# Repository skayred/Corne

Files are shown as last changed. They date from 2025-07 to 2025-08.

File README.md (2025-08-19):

# Budget Wireless Corne Keyboard Build

A DIY wireless split keyboard based on the Corne layout, built for approximately $25 USD. This project uses a ProMicro clone with nrf52840 chip, making it a cost-effective alternative to traditional wireless split keyboard builds.

## Features
- Fully wireless using Bluetooth
- Split ergonomic design (Corne layout)
- Low profile design for portability
- Battery-powered with power switch
- ZMK firmware
- Estimated battery life: 1+ month

## Bill of Materials

| Component | Quantity | Cost (USD) | Link |
|---|---|---|---|
| Controller boards (ProMicro nrf52840) | 2 | 6.82 | [AliExpress](https://a.aliexpress.com/_EIV3vwY) |
| Batteries | 2 | 4.20 | [AliExpress](https://a.aliexpress.com/_Eynt9TK) |
| Mechanical Switches | 50 | 7.47 | [AliExpress](https://a.aliexpress.com/_EGhMxEC) |
| Keycaps | Set | 3.79 | [Option 1](https://a.aliexpress.com/_EzQyNtA) / [Option 2](https://a.aliexpress.com/_EH8mNqs) |
| Diodes (1N4148) | 100 | 0.85 | [AliExpress](https://a.aliexpress.com/_EwZoG2G) |
| Slide Switches | 2 | 0.11 | |
| 3D Printed Parts | Set | 1.80 | Files provided |

**Total Cost**: $25.04 (excluding wires and screws)

## Current Keymap







## Build Instructions

### Prerequisites
- Basic soldering skills
- Access to a 3D printer
- Basic understanding of keyboard firmware

### Case Assembly
1. Print the case files (STL files provided in `3DFiles` directory)
2. Note: You may need to adjust the:
   - Battery compartment size
   - Slide switch holes

### Wiring
1. Wire switches in a matrix configuration
2. Connect diodes:
   - Direction matters (black line indicates cathode)
   - Use diode legs for the rows
   - Use separate wires for columns
3. Keep wiring clear of screw holes
4. Connect the battery:
   - GND to GND pin
   - Positive to one of the side legs on the slide switch
   - Middle pin of the slide switch to the RAW pin

### Pin Connections for Rows and Columns
The matrix configuration uses GPIO pins on the nRF52840 Pro Micro clone. Below are the connections:

pinout

#### How Rows and Columns Are Numbered

- **Rows**: Rows are always numbered from top to bottom on both halves.
- **Columns**: Columns are always numbered from left to right (as viewed from the back of the plate (where the wiring is done)).

⚠️ **Note**: If you accidentally solder the rows or columns to the wrong pins, you do not need to desolder. The mappings can be fixed in the firmware configuration files:
- `corne.dtsi`: Defines rows for both halves.
- `corne_left.overlay`: Defines columns for the left half.
- `corne_right.overlay`: Defines columns for the right half.

#### Left Half Pin Assignments
- **Rows (Connected to `row-gpios`)**:
  - Row 0: Pin 21
  - Row 1: Pin 20
  - Row 2: Pin 19
  - Row 3: Pin 18
- **Columns (Connected to `col-gpios`)**:
  - Column 0: Pin 2
  - Column 1: Pin 7
  - Column 2: Pin 6
  - Column 3: Pin 5
  - Column 4: Pin 4
  - Column 5: Pin 3

#### Right Half Pin Assignments
- **Rows (`row-gpios`)**:
  - Row 0: Pin 21
  - Row 1: Pin 20
  - Row 2: Pin 19
  - Row 3: Pin 18
- **Columns (`col-gpios`)**:
  - Column 0: Pin 3
  - Column 1: Pin 4
  - Column 2: Pin 5
  - Column 3: Pin 6
  - Column 4: Pin 7
  - Column 5: Pin 2

### Firmware Setup
This keyboard uses ZMK firmware. The left half acts as the main controller that connects to your device.

To flash the firmware:
1. Double press the reset button
2. Board will appear as mass storage device
3. Flash the appropriate firmware file

If you forgot the keyboard from your device and can't reconnect:
1. Flash the `settings_reset-nice_nano_v2-zmk.uf2` file
2. Reflash the regular firmware
3. Pair

## Repository Structure
```
├── .github/workflows/
│   └── build.yml
├── 3DFiles/
│   ├── STEP/
│   │   └── CorneSTEP.step
│   ├── STL/
│   │   ├── Case_Left.stl
│   │   ├── Case_Right.stl
│   │   └── PlateCorne.stl
├── config/
│   ├── boards/shields/corne/
│   │   ├── corne_left.conf
│   │   ├── corne_left.overlay
│   │   ├── corne_right.conf
│   │   ├── corne_right.overlay
│   │   ├── corne.conf
│   │   ├── corne.dtsi
│   │   ├── Kconfig.defconfig
│   │   └── Kconfig.shield
│   ├── corne.keymap
│   └── west.yml
├── firmware/
│   ├── corne_left-nice_nano_v2-zmk.uf2
│   ├── corne_right-nice_nano_v2-zmk.uf2
│   └── settings_reset-nice_nano_v2-zmk.uf2
└── zephyr/
    ├── module.yml
    └── build.yaml
```

## Known Issues
- Left side case may have warping issues if battery swells
- Slide switch holes may need adjustment based on your components

## Final result
im1
im3

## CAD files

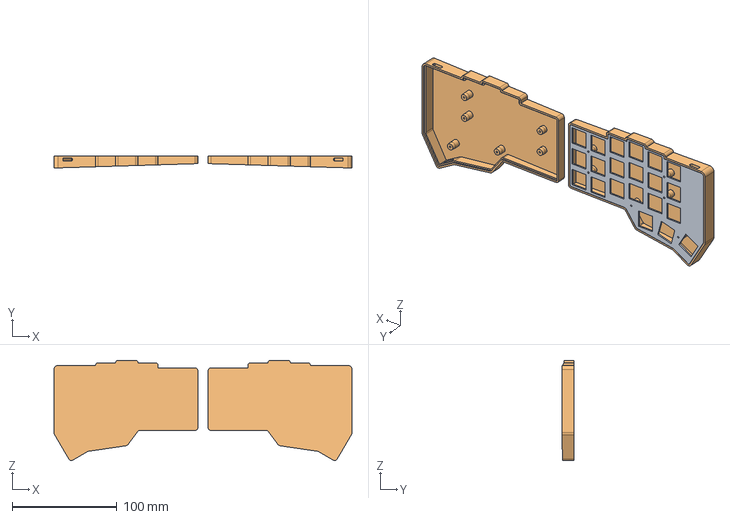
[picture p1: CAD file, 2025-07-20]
3DFiles/STEP/CorneSTEP.step
284.0 x 11.5 x 95.4 mm

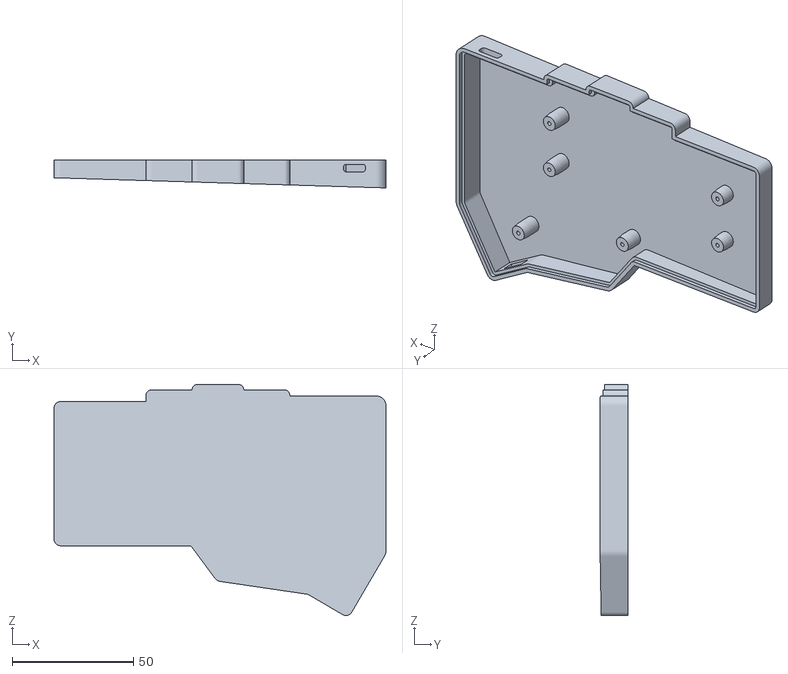
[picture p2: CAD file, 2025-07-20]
3DFiles/STL/Case_Right.stl
137.1 x 11.5 x 95.4

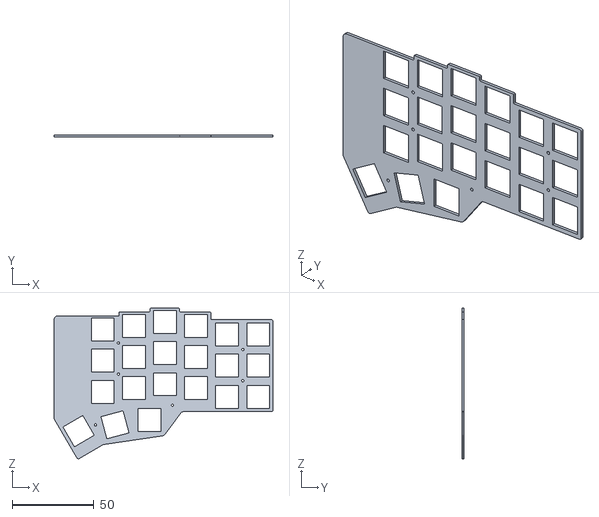
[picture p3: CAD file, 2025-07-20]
3DFiles/STL/PlateCorne.stl
133.8 x 1.35 x 92.0

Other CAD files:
3DFiles/STL/Case_Left.stl

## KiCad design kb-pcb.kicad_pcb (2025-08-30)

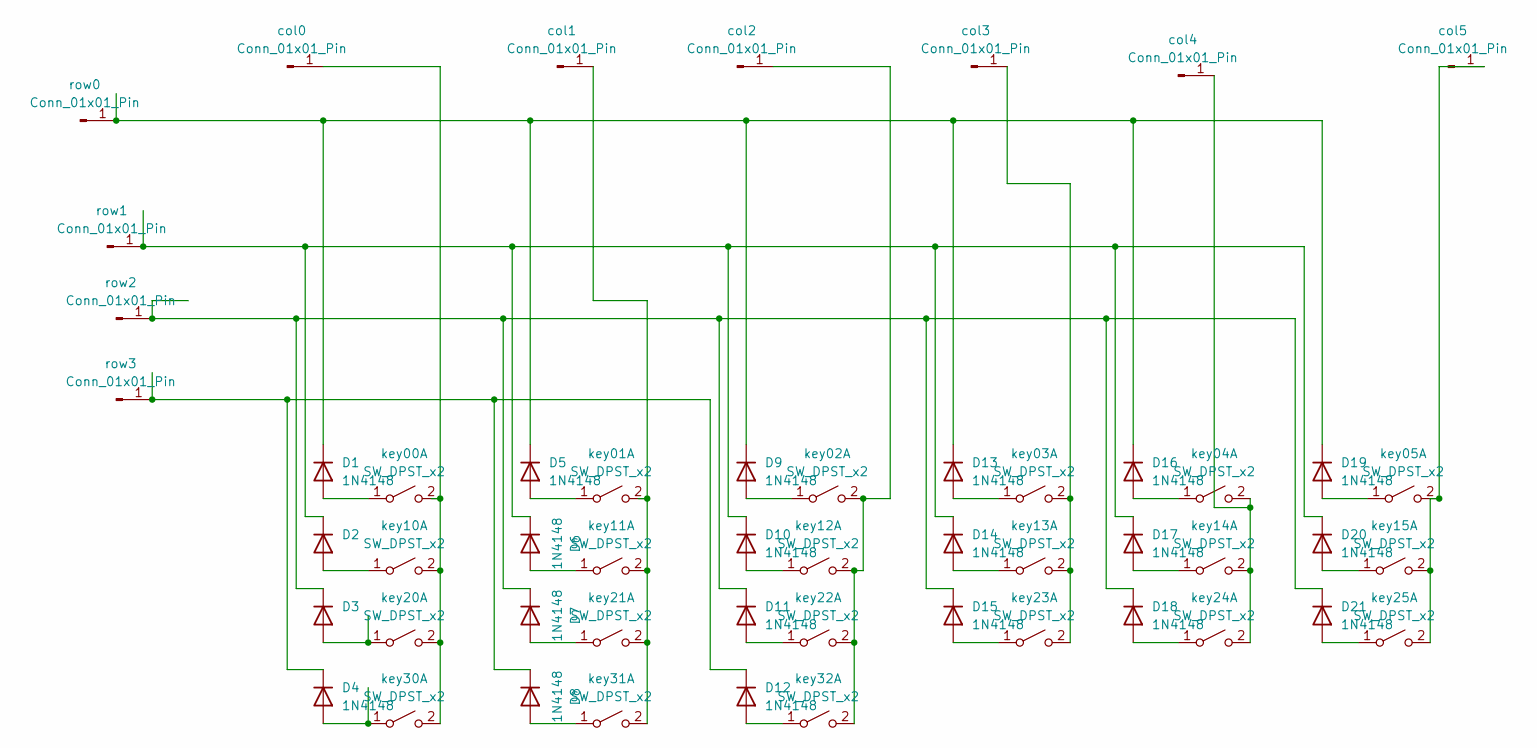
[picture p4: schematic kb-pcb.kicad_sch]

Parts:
D1, D2, D3, D4, D5, D6, D7, D8, D9, D10, D11, D12, D13, D14, D15, D16, D17, D18, D19, D20, D21: 1N4148; D_DO-35_SOD27_P7.62mm_Horizontal
col0, col1, col2, col3, col4, col5: Conn_01x01_Pin; PinSocket_1x01_P1.27mm_Vertical
key00, key01, key02, key03, key04, key05, key10, key11, key12, key13, key14, key15, key20, key21, key22, key23, key24, key25, key30, key31, key32: SW_DPST_x2; SW_Redragon_LowProfile_PCB_1.00u
row0, row1, row2, row3: Conn_01x01_Pin; PinSocket_1x01_P1.27mm_Vertical

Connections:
unnamed: D1.2 (A), key00.1 (A)
unnamed: D1.1 (K), D5.1 (K), D9.1 (K), D13.1 (K), D16.1 (K), D19.1 (K), row0.1
unnamed: D2.2 (A), key10.1 (A)
unnamed: D3.2 (A), key20.1 (A)
unnamed: D4.2 (A), key30.1 (A)
unnamed: D5.2 (A), key01.1 (A)
unnamed: D6.2 (A), key11.1 (A)
unnamed: D7.2 (A), key21.1 (A)
unnamed: D8.2 (A), key31.1 (A)
unnamed: D9.2 (A), key02.1 (A)
unnamed: D10.2 (A), key12.1 (A)
unnamed: D2.1 (K), D6.1 (K), D10.1 (K), D14.1 (K), D17.1 (K), D20.1 (K), row1.1
unnamed: D11.2 (A), key22.1 (A)
unnamed: D3.1 (K), D7.1 (K), D11.1 (K), D15.1 (K), D18.1 (K), D21.1 (K), row2.1
unnamed: D12.2 (A), key32.1 (A)
unnamed: D4.1 (K), D8.1 (K), D12.1 (K), row3.1
unnamed: D13.2 (A), key03.1 (A)
unnamed: D14.2 (A), key13.1 (A)
unnamed: D15.2 (A), key23.1 (A)
unnamed: D16.2 (A), key04.1 (A)
unnamed: D17.2 (A), key14.1 (A)
unnamed: D18.2 (A), key24.1 (A)
unnamed: D19.2 (A), key05.1 (A)
unnamed: D20.2 (A), key15.1 (A)
unnamed: D21.2 (A), key25.1 (A)
unnamed: col0.1, key00.2 (B), key10.2 (B), key20.2 (B), key30.2 (B)
unnamed: col1.1, key01.2 (B), key11.2 (B), key21.2 (B), key31.2 (B)
unnamed: col2.1, key02.2 (B), key12.2 (B), key22.2 (B), key32.2 (B)
unnamed: col3.1, key03.2 (B), key13.2 (B), key23.2 (B)
unnamed: col4.1, key04.2 (B), key14.2 (B), key24.2 (B)
unnamed: col5.1, key05.2 (B), key15.2 (B), key25.2 (B)

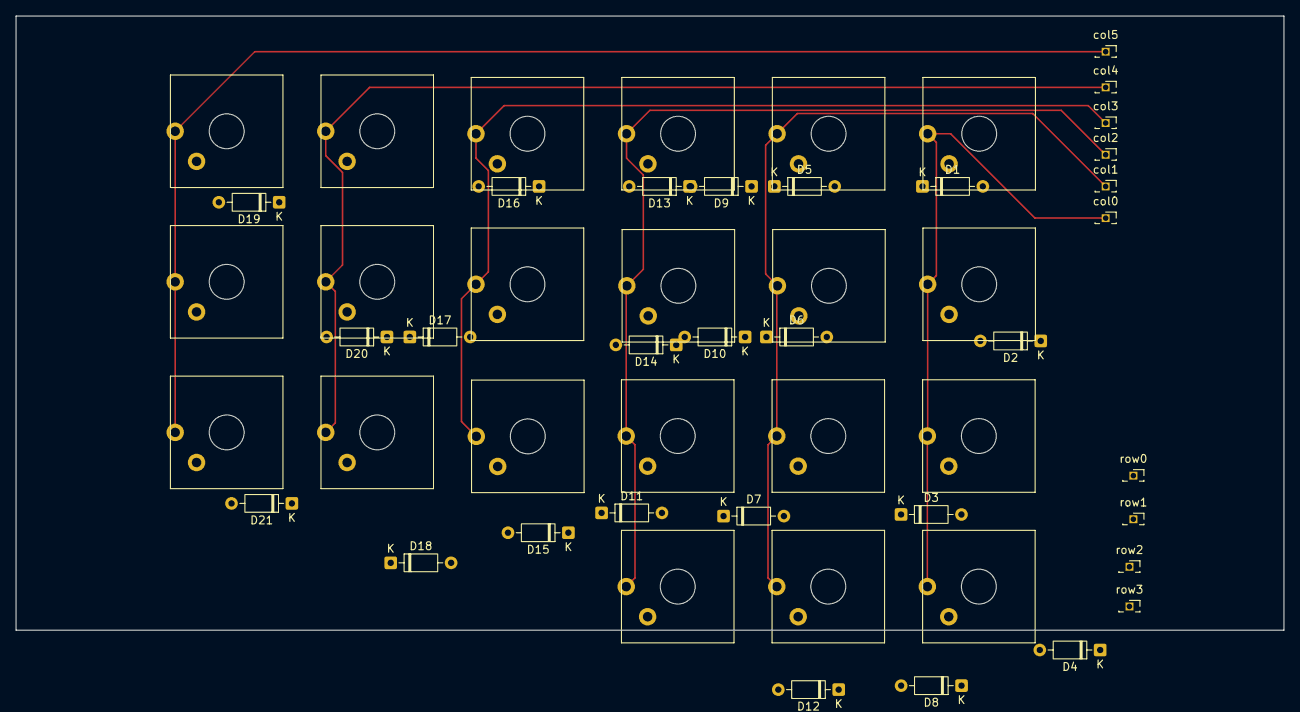
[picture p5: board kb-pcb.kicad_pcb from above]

Board: 2 copper layers, 160.0 x 77.5 mm, 52 parts (0 on the bottom side), 31 nets.

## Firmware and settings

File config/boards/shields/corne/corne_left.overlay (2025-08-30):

#include "corne.dtsi"

&kscan0 {
    col-gpios = <&pro_micro 2 GPIO_ACTIVE_HIGH>,
                <&pro_micro 3 GPIO_ACTIVE_HIGH>,
                <&pro_micro 4 GPIO_ACTIVE_HIGH>,
                <&pro_micro 5 GPIO_ACTIVE_HIGH>,
                <&pro_micro 6 GPIO_ACTIVE_HIGH>,
                <&pro_micro 7 GPIO_ACTIVE_HIGH>;
};


#define MOUSE_PS2_DRIVER_UART
#define MOUSE_PS2_PIN_SCL_PRO_MICRO <&pro_micro 1 GPIO_ACTIVE_HIGH>
#define MOUSE_PS2_PIN_SDA_PRO_MICRO <&pro_micro 0 GPIO_ACTIVE_HIGH>
#define MOUSE_PS2_PIN_RST_PRO_MICRO <&pro_micro 9 GPIO_ACTIVE_HIGH>
#define MOUSE_PS2_PIN_SDA_PINCTRL <NRF_PSEL(UART_RX, 0, 8)>
#define MOUSE_PS2_UART_BAUD_RATE <14400>


/*
 * PS/2 Mouse / Trackpoint - User Configuration if NOT using nice!nano
 *
 * WARNING: Do NOT change this if you are using a nice!nano v2 or clone.
 */

// Unexposed UART pins
// In UART two different pins are used for receiving and transmitting, but PS/2
// uses the same pin for both.
//
// The UART config still requires both pins to be configured. So we use one of
// the nrf52 pins that are not exposed on the nice!nano board.
//
// Do NOT change these if you are using a nice!nano (or a clone of it)
#define MOUSE_PS2_PIN_UNEXPOSED_TX <NRF_PSEL(UART_TX, 0, 27)>
#define MOUSE_PS2_PIN_UNEXPOSED_RX <NRF_PSEL(UART_RX, 0, 28)>


// Adjust GPIO interrupt priority to the highest level.
//
// IMPORTANT TLDR:
// If you are using the nice_nano_v2 board, you don't need to make changes to
// the config below and can leave it as it is.
//
// Explanation of these settings:
//
// PS/2 events must be processed within 30-50us, but frequently bluetooth and
// other interrupts take longer to finish.
//
// Therefore we change the default GPIO priority to the highest level (0) and
// demote all BT interrupt priorities by one level using the kconfig settings:
// - CONFIG_BT_CTLR_LLL_PRIO 1
// - CONFIG_BT_CTLR_ULL_HIGH_PRIO 2
// - CONFIG_BT_CTLR_ULL_LOW_PRIOCONFIG 2
//
// These config options are enabled automatically by the PS2 UART and GPIO
// drivers... so you don't have to enable them manually.
//
// Then we lower the interrupt priority of all other devices by 2 levels using
// the devicetree config below.
//
// This allows the PS/2 interrupts to be triggered faster and reduces
// transmission errors.
//
// If you are using the nice_nano_v2 board, you can reuse my config below.
//
// Otherwise, you can generate the interrupt overrides using this script:
// https://github.com/infused-kim/kb_zmk_ps2_mouse_trackpoint_driver/blob/main/scripts/gen_interrupt_priority_overrides.py
//
// Make sure to do it on a zephyr.dts where the interrupts have not been
// adjusted yet (i.e. a config that doesn't have the the following options
// enabled).
//
// If you are building using a toolchain you can find the zephyr.dts in the
// build directory, which by default is: `app/build/zephyr/zephyr.dts`
//
// If you are building using the github actions, copy the output of the build
// step `xxxx_right - nice_nano_v2 Devicetree file` into a file and run the
// script on it.

// gpiote should have the highest interrupt priority (0)
&gpiote {
    interrupts = < 6 0 >;
};

// All other priorities should be two levels lower than their defaults
// (which is usually 1 and should be demoted to 3)
&clock {
    interrupts = < 0 3 >;
};

&power {
    interrupts = < 0 3 >;
};

&radio {
    interrupts = < 1 3 >;
};

&uart0 {
    interrupts = < 2 3 >;
};

&i2c0 {
    interrupts = < 3 3 >;
};

&spi0 {
    interrupts = < 3 3 >;
};

&i2c1 {
    interrupts = < 4 3 >;
};

&spi1 {
    interrupts = < 4 3 >;
};

&nfct {
    interrupts = < 5 3 >;
};

&adc {
    interrupts = < 7 3 >;
};

&timer0 {
    interrupts = < 8 3 >;
};

&timer1 {
    interrupts = < 9 3 >;
};

&timer2 {
    interrupts = < 10 3 >;
};

&rtc0 {
    interrupts = < 11 3 >;
};

&temp {
    interrupts = < 12 3 >;
};

&rng {
    interrupts = < 13 3 >;
};

&ecb {
    interrupts = < 14 3 >;
};

&ccm {
    interrupts = < 15 3 >;
};

&wdt {
    interrupts = < 16 3 >;
};

&rtc1 {
    interrupts = < 17 3 >;
};

&qdec {
    interrupts = < 18 3 >;
};

&comp {
    interrupts = < 19 3 >;
};

&egu0 {
    interrupts = < 20 3 >;
};

&egu1 {
    interrupts = < 21 3 >;
};

&egu2 {
    interrupts = < 22 3 >;
};

&egu3 {
    interrupts = < 23 3 >;
};

&egu4 {
    interrupts = < 24 3 >;
};

&egu5 {
    interrupts = < 25 3 >;
};

&timer3 {
    interrupts = < 26 3 >;
};

&timer4 {
    interrupts = < 27 3 >;
};

&pwm0 {
    interrupts = < 28 3 >;
};

&pdm0 {
    interrupts = < 29 3 >;
};

&pwm1 {
    interrupts = < 33 3 >;
};

&pwm2 {
    interrupts = < 34 3 >;
};

&spi2 {
    interrupts = < 35 3 >;
};

&rtc2 {
    interrupts = < 36 3 >;
};

&i2s0 {
    interrupts = < 37 3 >;
};

&usbd {
    interrupts = < 39 3 >;
};

&uart1 {
    interrupts = < 40 3 >;
};

&qspi {
    interrupts = < 41 3 >;
};

&pwm3 {
    interrupts = < 45 3 >;
};

&spi3 {
    interrupts = < 47 3 >;
};

&cryptocell {
    interrupts = < 42 3 >;
};
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

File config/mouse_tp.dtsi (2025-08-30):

#ifdef HAS_MOUSE_TP
  #include <dt-bindings/zmk/mouse.h>
  #include <dt-bindings/zmk/mouse_settings.h>
  #include <behaviors/mouse_keys.dtsi>
  #include <behaviors/mouse_setting.dtsi>

 /*
  * Key Behaviors to adjust settings
  */

  // They key codes below can be used to adjust the TP settings at runtime
  // without needing to recompile the firmware.
  //
  // The values will be logged and saved in the config on the controller flash
  // after 60s (CONFIG_ZMK_SETTINGS_SAVE_DEBOUNCE).
  //
  // On boot the settings will be restored again.
  //
  // If you prefer a more explicit way of configuration, you can also hardcode
  // these settings in `&mouse_ps2`.
  //
  // If you set these settings in `&mouse_ps2`, you will still be able to
  // adjust the values during runtime with these key codes, but after
  // restarting the board the values in `&mouse_ps2` will be restored and not
  // the ones stored in the flash using the key codes.


  // How sensitive the trackpoint is
  #define U_MSS_TP_S_I &mms MS_TP_SENSITIVITY_INCR
  #define U_MSS_TP_S_D &mms MS_TP_SENSITIVITY_DECR


  // The maximum speed the trackpoint will accelerate to
  #define U_MSS_TP_V6_I &mms MS_TP_VALUE6_INCR
  #define U_MSS_TP_V6_D &mms MS_TP_VALUE6_DECR


  // I am not quite sure tbh... default seems fine.
  #define U_MSS_TP_NI_I &mms MS_TP_NEG_INERTIA_INCR
  #define U_MSS_TP_NI_D &mms MS_TP_NEG_INERTIA_DECR


  // How hard you have to press to activate the "Press To Select" feature that
  // lets you tap or press on the trackpoint to click.
  //
  // Not all trackpoints support it and you have to enable
  // `tp-press-to-select;` in `&mouse_ps2` first.
  #define U_MSS_TP_PT_I &mms MS_TP_PTS_THRESHOLD_INCR
  #define U_MSS_TP_PT_D &mms MS_TP_PTS_THRESHOLD_DECR


  // If you mess up the settings, you can use this key code to clear the
  // settings from flash and re-set the default values on the TP.
  //
  // Make sure to wait at least CONFIG_ZMK_SETTINGS_SAVE_DEBOUNCE seconds (60
  // by default) before restarting the board to ensure the settings are
  // written to flash storage.
  #define U_MSS_RESET   &mms MS_RESET


  // If you prefer to set the settings in `&mouse_ps2`, you can use the key
  // codes above to find the settings you like the most and then press this
  // key code to output the settings to the log.
  //
  // Then you can add those values to `&mouse_ps2`
  #define U_MSS_LOG     &mms MS_LOG


  // Only apply these settings on the side that has the TP connected
  // (usually the right side)
  #ifdef MOUSE_PS2_DT_PRESENT

   /*
    * Input Listener Config
    */

    &mouse_ps2_input_listener {

      // Adjust pointing device axes.
      // This adjusts the values inside the zmk driver. Some
      // trackpoints also allow you to adjust it in their firmware. Check
      // the driver options below for more info.
      // xy-swap;
      // x-invert;
      // y-invert;

      // Set the layer that should automatically activate when the mouse is
      // moving.
      layer-toggle = <MOUSE_TP>;

      // How long the mouse needs to move for before the layer is activated (to
      // avoid accidental activations while typing) (Default: 250)
      layer-toggle-delay-ms = <250>;

      // How long to wait, after the last mouse movement, before deactivating
      // the layer (Default: 250)
      layer-toggle-timeout-ms = <250>;
    };


   /*
    * Mouse Driver Settings
    */

    &mouse_ps2 {

      // How sensitive the TP is (Default: 128)
      // tp-sensitivity = <128>;


      // The maximum mouse movement speed the TP will accelarate to
      // (Default: 97)
      // tp-val6-upper-speed = <97>;


      // Negative Inertia (Default: 6)
      // Makes the TP feel more responsive and "overshoot" less.
      // tp-neg-inertia = <6>;


      // Enable clicking by tapping on the TP.
      // Not all TPs support this.
      // tp-press-to-select;
      // tp-press-to-select-threshold = <10>;


      // Adjust axis settings on the TP
      // Works only on some trackpoints, but may be properly considered by the
      // trackpoint's acceleration features (which may or may not have an
      // impact).
      //
      // Alternatively consider achieving the same effect using the
      //  `input-listener` settings below.
      // tp-xy-swap;
      // tp-x-invert;
      // tp-y-invert;


      // Set sampling rate
      //
      // The frequency at which the mouse samples and sends data (in hz).
      // The default rate is 100. You can try lowering it if you experience
      // connection errors.
      //
      // Higher values than 100 are no improvement in my experience, but will
      // increase battery life and potentially errors in transmissions.
      //
      // These values are allowed: 10,20,40,60,80,100,200
      // sampling-rate = <60>;
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

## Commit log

2025-07-20 Add STEP files for CAD editing (closes #1 )
    Sorry for the delay the STEP files are now included.
    [Case_Left.stl, Case_Right.stl, CorneSTEP.step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]
2025-08-30 PS/2 added
    [kb-pcb.kicad_pcb, kb-pcb.kicad_sch]
